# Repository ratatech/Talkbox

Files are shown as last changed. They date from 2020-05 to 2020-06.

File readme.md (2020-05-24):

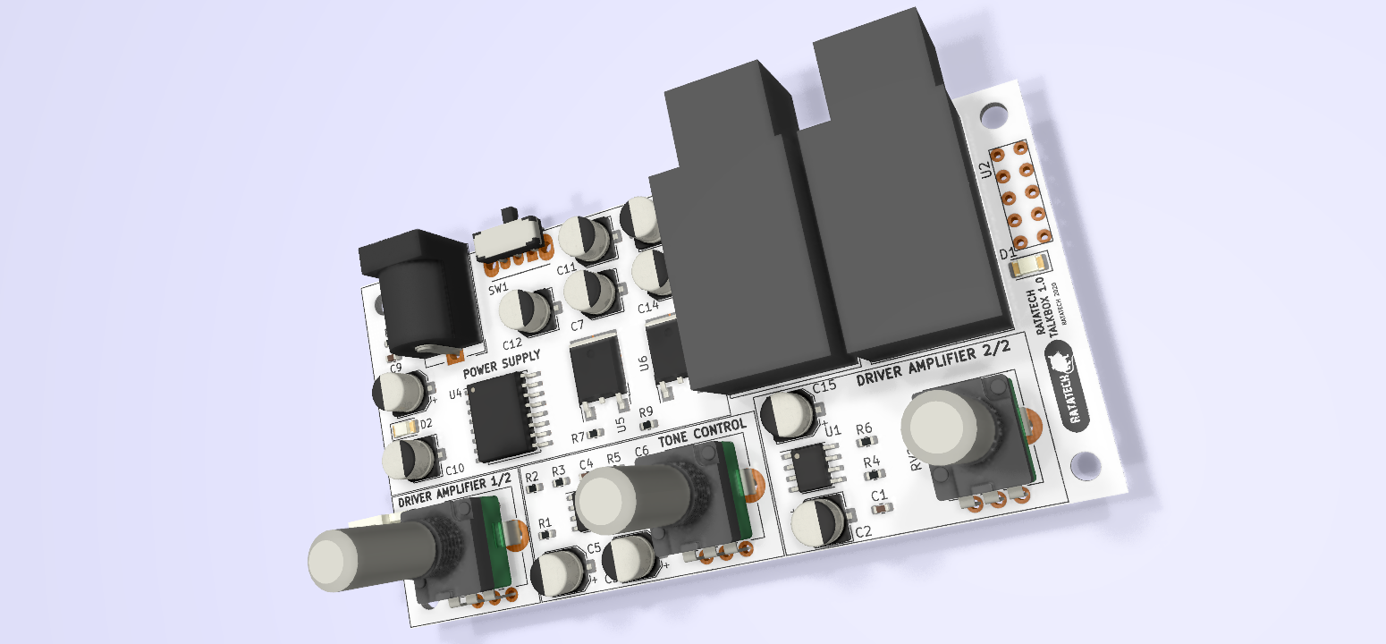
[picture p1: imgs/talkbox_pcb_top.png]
Ratatech Talkbox pcb top view


# Ratatech Talkbox

This repository contains mainly the PCB design files for the Ratatech Talkbox unit. 

DESCRIPTION WIP.

## Files

* [datasheets](./datasheets) 	Datasheets of some of the components and schematics used in this project.
* [imgs](./imgs) 				Images used in the design and captures or the 3d models/final pcb.
* [kicad](./kicad) 				Main Kicad project directory. Including schematics and pcb.

---

## License



- **[MIT license](http://opensource.org/licenses/mit-license.php)**

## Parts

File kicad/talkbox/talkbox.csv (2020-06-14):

Reference | Quantity | Value | Footprint | Datasheet | Mouser part
C10 | 1 | 0.002uF | Capacitor_SMD:C_0603_1608Metric | ~ | 603-CC603KRX7R9BB202
C11 C5 C4 | 3 | 100uF | Capacitor_SMD:CP_Elec_5x5.3 | ~ | 661-EMZJ6R3A101ME61G
C13 C12 C8 | 3 | 2uF | Capacitor_SMD:CP_Elec_5x5.3 | ~ | 661-EMVE630ADA3R3ME5
C15 C14 | 2 | 1uF | Capacitor_SMD:CP_Elec_5x5.3 | ~ | RVS-50V010MU-R
C3 | 1 | 6.8nF | Capacitor_SMD:C_0603_1608Metric | ~ | 710-885012206088
C6 | 1 | 10nF | Capacitor_SMD:C_0603_1608Metric | ~ | 710-885012206040
C7 | 1 | 47nF | Capacitor_SMD:C_0603_1608Metric | ~ | 140-VE470M1CTR0505
C9 C2 C1 | 3 | 10uF | Capacitor_SMD:CP_Elec_5x5.3 | ~ | 598-AVE106M35C12T-F
D2 D1 | 2 | LED | LED_SMD:LED_1206_3216Metric | ~ | 327-BR1101WTR
H1 H3 H2 H4 | 4 | MountingHole | MountingHole:MountingHole_3mm | ~
J1 J4 | 2 | AudioJack2 | Connector_Audio_Extended:Jack_6.35mm_Neutrik_NRJ4HF-1_Horizontal | ~ | 550-10284G
J2 | 1 | Barrel_Jack_Switch | Connector_BarrelJack:BarrelJack_CUI_PJ-102AH_Horizontal | ~ | 490-PJ-102BH
J3 | 1 | Conn_02x04_Odd_Even | Connector_PinHeader_2.54mm:PinHeader_2x04_P2.54mm_Vertical | ~
R1 | 1 | 1000k | Resistor_SMD:R_0603_1608Metric | ~ | 667-ERJ-3GEYJ105V
R2 | 1 | 2k | Resistor_SMD:R_0603_1608Metric | ~ | 71-CRCW06032K00FKEAC
R3 | 1 | 47K | Resistor_SMD:R_0603_1608Metric | ~ | 71-CRCW060347K0FKEAC
R5 R4 | 2 | 22K | Resistor_SMD:R_0603_1608Metric | ~ | 71-CRCW060322K0FKEAC
R6 | 1 | 240K | Resistor_SMD:R_0603_1608Metric | ~ | 652-CR0603FX-2403ELF
R8 R7 | 2 | 470 | Resistor_SMD:R_0603_1608Metric | ~ | 71-CRCW0603470RFKEAC
RV2 RV1 | 2 | 20K | Potentiometer_THT:Potentiometer_Alps_RK09K_Single_Vertical | ~ | 652-PTV09A-4030UB203
RV3 | 1 | 10K | Potentiometer_THT:Potentiometer_Alps_RK09K_Single_Vertical | ~ | 652-PTV09A-4025FB103
SW1 | 1 | SW_SPST | Button_Switch_THT:SW_CuK_OS102011MA1QN1_SPDT_Angled | ~ | 611-OS102011MA1QN1
U1 | 1 | TL071 | Package_SO:SOIC-8_3.9x4.9mm_P1.27mm | http://www.ti.com/lit/ds/symlink/tl071.pdf | 511-TL071CDT
U2 | 1 | logo | imgs:ratatech_bitmap_10x2.8mm
U3 | 1 | LT1054xSOIC16 | Package_SO:SOIC-16W_7.5x10.3mm_P1.27mm |  | 595-LT1054CDWR
U4 | 1 | SW_3PDT | Connector_PinHeader_2.54mm:PinHeader_2x05_P2.54mm_Vertical |  | 612-FS573PLT2B2M1QE
U5 | 1 | LM7812_TO220 | Package_TO_SOT_SMD:ATPAK-2 | http://www.fairchildsemi.com/ds/LM/LM7805.pdf | 511-L78M12CDT-TR
U6 | 1 | LM7912_TO220 | Package_TO_SOT_SMD:ATPAK-2 | http://www.fairchildsemi.com/ds/LM/LM7905.pdf | 512-KA79M12RTF

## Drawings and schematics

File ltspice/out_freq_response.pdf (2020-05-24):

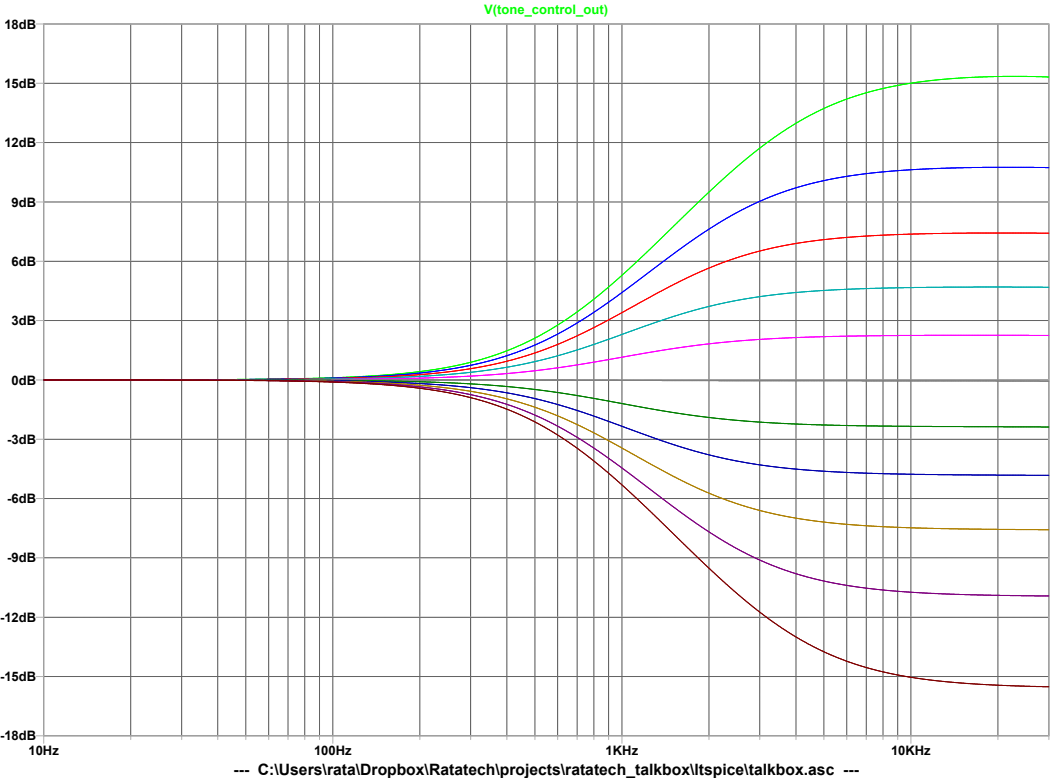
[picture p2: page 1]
1KHz; 10KHz; V(tone_control_out)

--- C:\Users\rata\Dropbox\Ratatech\projects\ratatech_talkbox\ltspice\talkbox.asc ---

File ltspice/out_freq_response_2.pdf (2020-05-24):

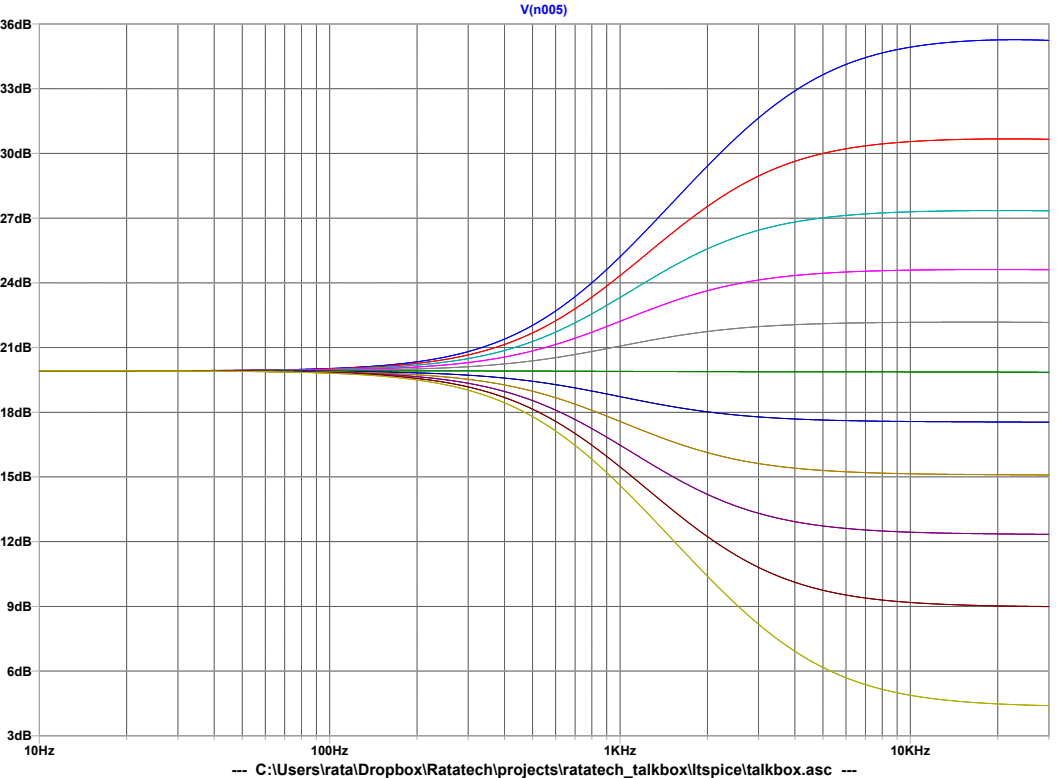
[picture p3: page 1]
1KHz; 10KHz

--- C:\Users\rata\Dropbox\Ratatech\projects\ratatech_talkbox\ltspice\talkbox.asc ---

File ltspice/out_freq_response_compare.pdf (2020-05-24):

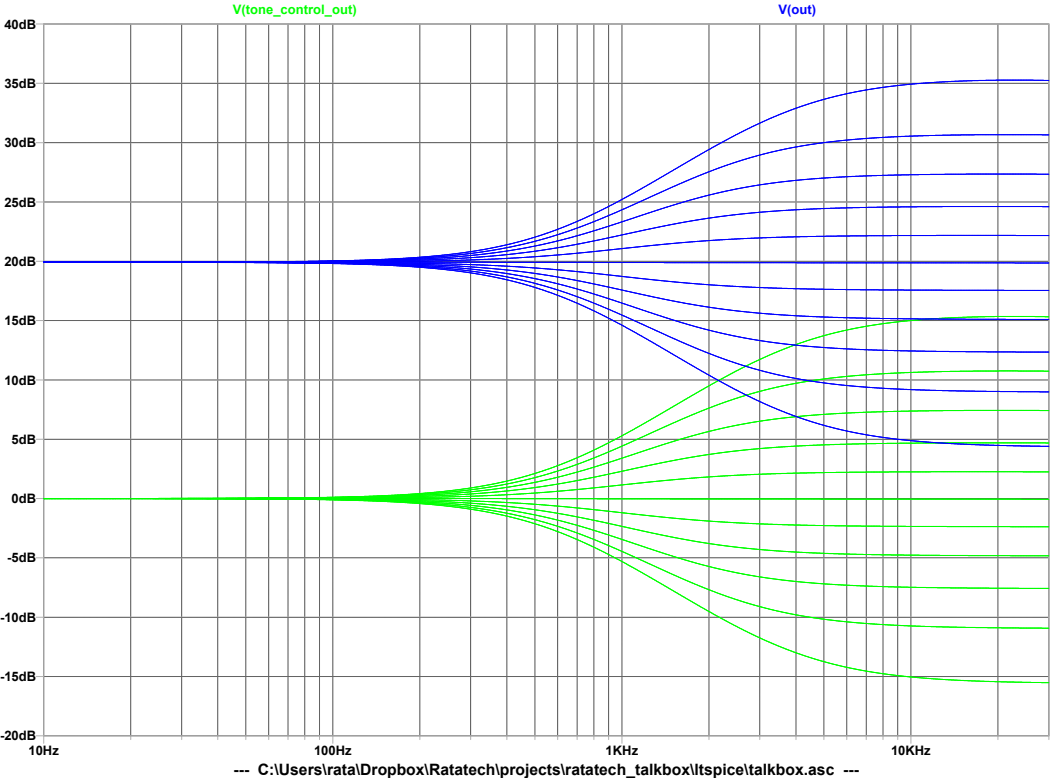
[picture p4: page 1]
1KHz; 10KHz; V(tone_control_out); V(out)

--- C:\Users\rata\Dropbox\Ratatech\projects\ratatech_talkbox\ltspice\talkbox.asc ---

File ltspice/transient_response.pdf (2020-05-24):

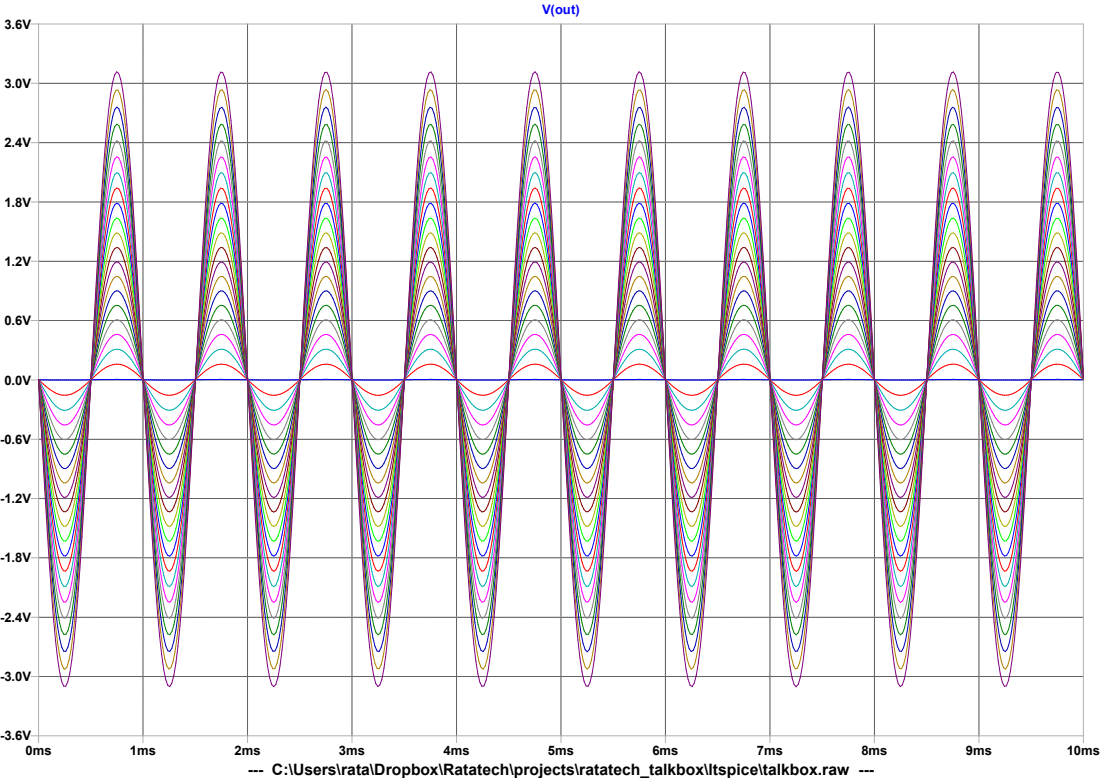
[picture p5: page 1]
V(out)

--- C:\Users\rata\Dropbox\Ratatech\projects\ratatech_talkbox\ltspice\talkbox.raw ---

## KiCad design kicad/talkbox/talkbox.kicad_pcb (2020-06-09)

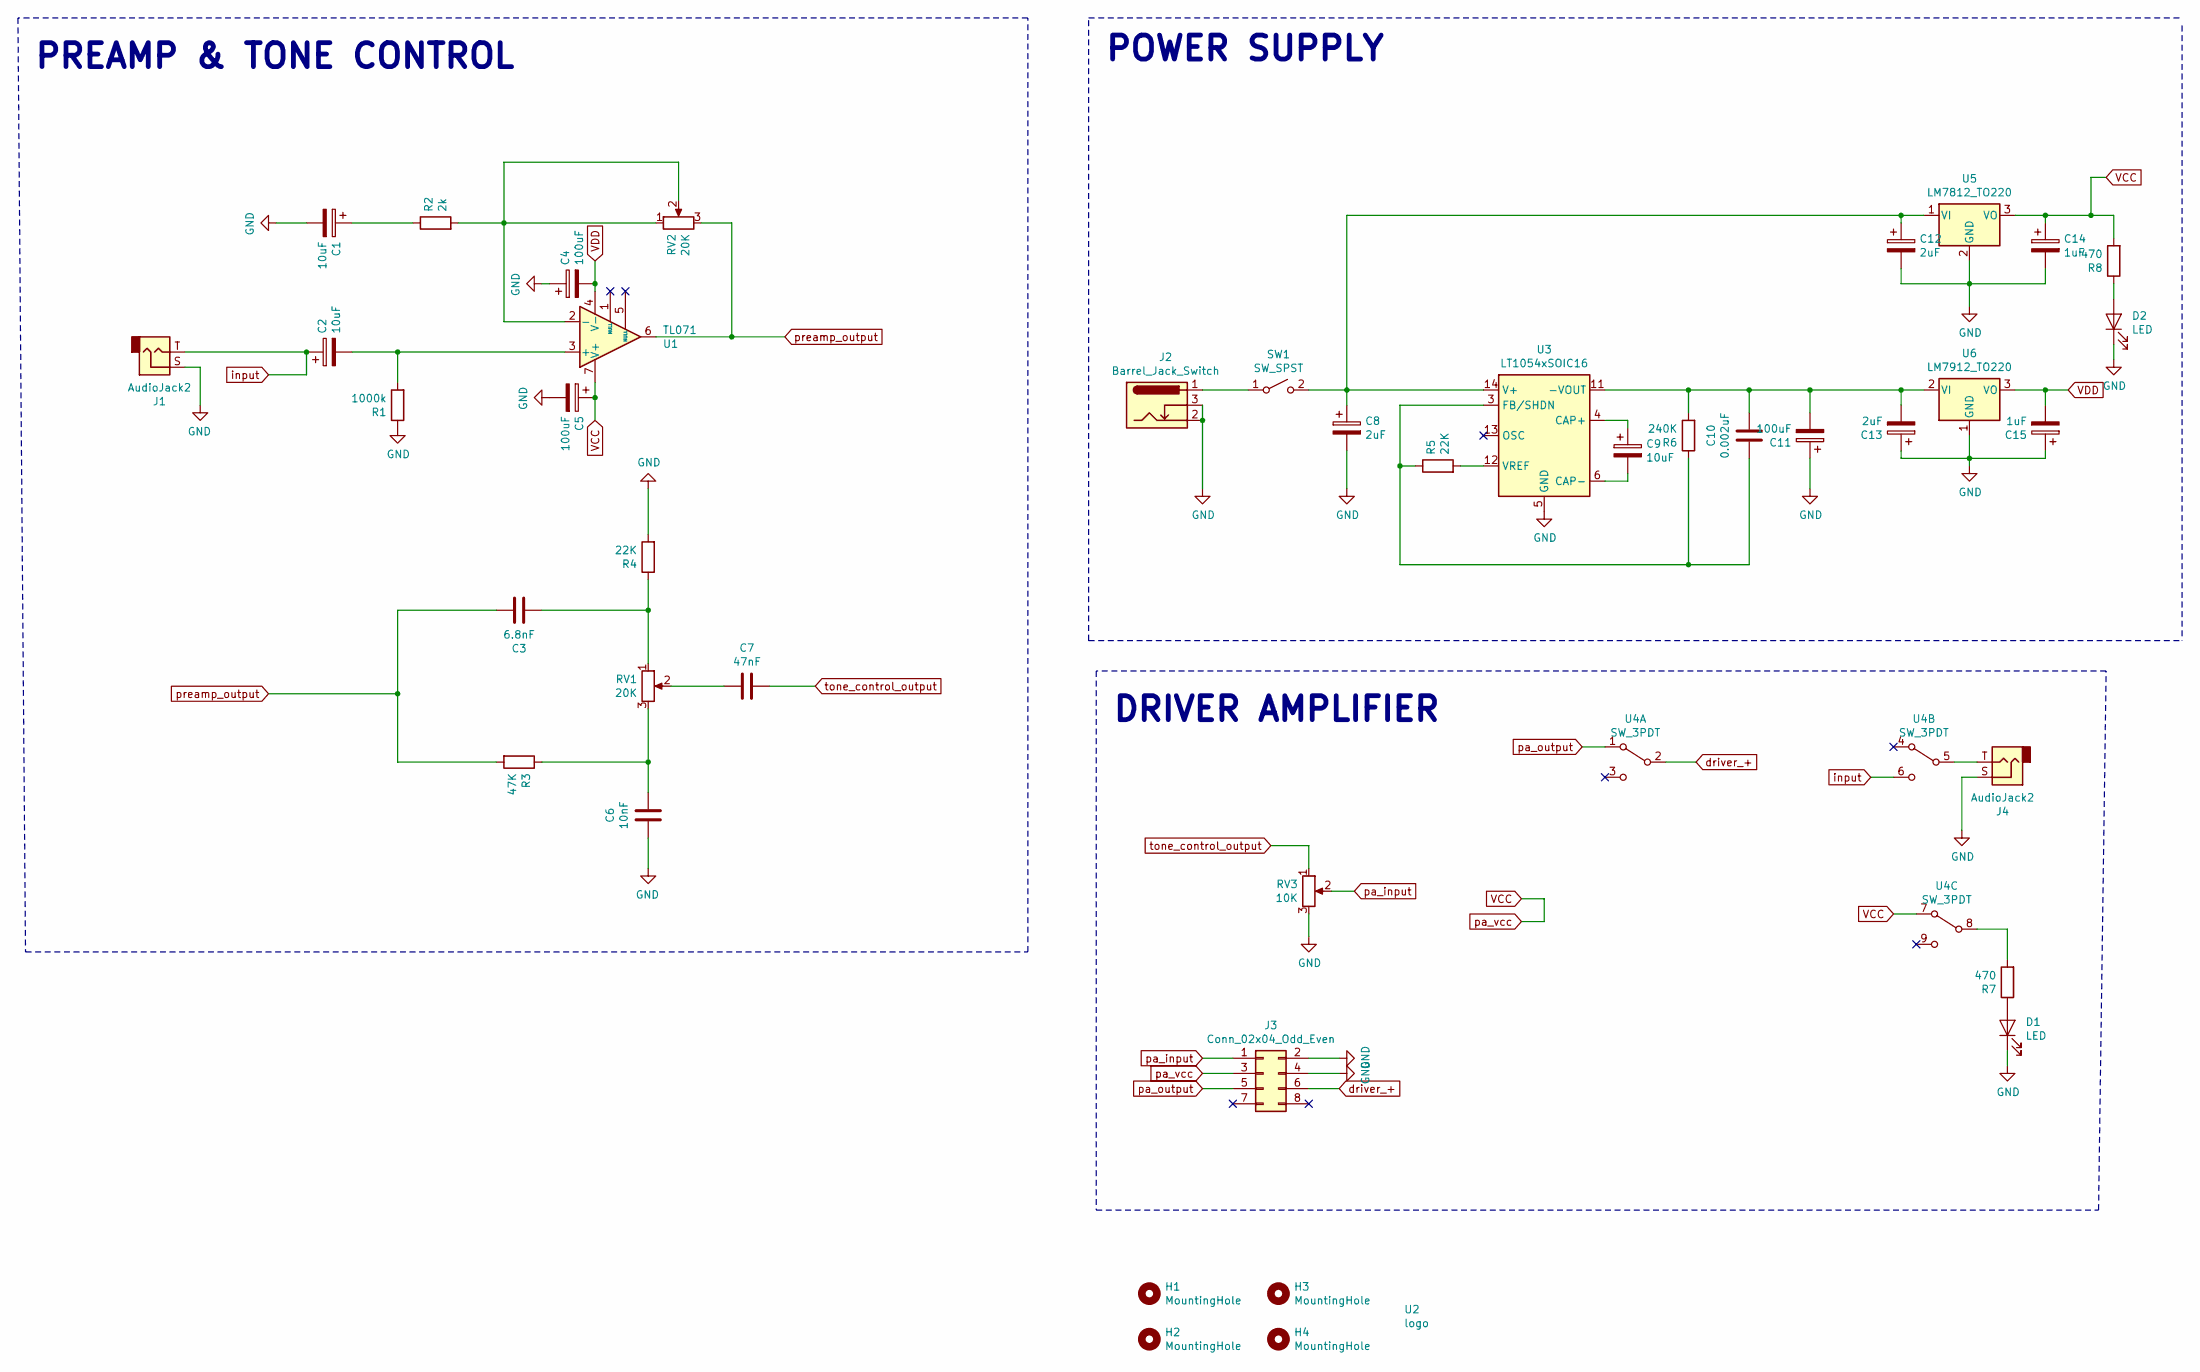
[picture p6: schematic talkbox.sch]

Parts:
C1, C2, C9: 10uF; CP_Elec_5x5.3
C3: 6.8nF; C_0603_1608Metric
C4, C5, C11: 100uF; CP_Elec_5x5.3
C6: 10nF; C_0603_1608Metric
C7: 47nF; C_0603_1608Metric
C8, C12, C13: 2uF; CP_Elec_5x5.3
C10: 0.002uF; C_0603_1608Metric
C14, C15: 1uF; CP_Elec_5x5.3
D1, D2: LED; LED_1206_3216Metric
H1, H2, H3, H4: MountingHole; MountingHole_3mm
J1, J4: AudioJack2; Jack_6.35mm_Neutrik_NRJ4HF-1_Horizontal
J2: Barrel_Jack_Switch; BarrelJack_CUI_PJ-102AH_Horizontal
J3: Conn_02x04_Odd_Even; PinHeader_2x04_P2.54mm_Vertical
R1: 1000k; R_0603_1608Metric
R2: 2k; R_0603_1608Metric
R3: 47K; R_0603_1608Metric
R4, R5: 22K; R_0603_1608Metric
R6: 240K; R_0603_1608Metric
R7, R8: 470; R_0603_1608Metric
RV1, RV2: 20K; Potentiometer_Alps_RK09K_Single_Vertical
RV3: 10K; Potentiometer_Alps_RK09K_Single_Vertical
SW1: SW_SPST; SW_CuK_OS102011MA1QN1_SPDT_Angled
U1: TL071; SOIC-8_3.9x4.9mm_P1.27mm
U2: logo; ratatech_bitmap_10x2.8mm
U3: LT1054xSOIC16; SOIC-16W_7.5x10.3mm_P1.27mm
U4: SW_3PDT; PinHeader_2x05_P2.54mm_Vertical
U5: LM7812_TO220; ATPAK-2
U6: LM7912_TO220; ATPAK-2

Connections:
GND: C1.2, C4.1, C5.2, C6.2, C8.2, C11.1, C12.2, C13.1, C14.2, C15.1, D1.1 (K), D2.1 (K), J1.S, J2.2, J2.3, J3.2, J3.4, J4.S, R1.1, R4.2, RV3.3, U3.5 (GND), U5.2 (GND), U6.1 (GND)
unnamed: C1.1, R2.1
unnamed: C2.2, R1.2, U1.3 (+)
unnamed: C3.2, R4.1, RV1.1
unnamed: C6.1, R3.1, RV1.3
unnamed: C7.2, RV1.2
unnamed: C9.1, U3.4 (CAP+)
unnamed: C9.2, U3.6 (CAP-)
unnamed: C10.1, C11.2, C13.2, R6.2, U3.11 (-VOUT), U6.2 (VI)
unnamed: C10.2, R5.1, R6.1, U3.3 (FB/SHDN)
unnamed: C8.1, C12.1, SW1.2 (B), U3.14 (V+), U5.1 (VI)
unnamed: D1.2 (A), R7.1
unnamed: D2.2 (A), R8.1
unnamed: J2.1, SW1.1 (A)
unnamed: J4.T, U4.5 (B)
unnamed: R2.2, RV2.1, RV2.2, U1.2 (-)
unnamed: R5.2, U3.12 (VREF)
unnamed: R7.2, U4.8 (B)
VCC: C5.1, C14.1, J3.3, R8.2, U1.7 (V+), U4.7 (A), U5.3 (VO)
VDD: C4.2, C15.2, U1.4 (V-), U6.3 (VO)
driver_+: J3.6, U4.2 (B)
input: C2.1, J1.T, U4.6 (C)
pa_input: J3.1, RV3.2
pa_output: J3.5, U4.1 (A)
preamp_output: C3.1, R3.2, RV2.3, U1.6
tone_control_output: C7.1, RV3.1

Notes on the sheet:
PREAMP & TONE CONTROL
POWER SUPPLY
DRIVER AMPLIFIER

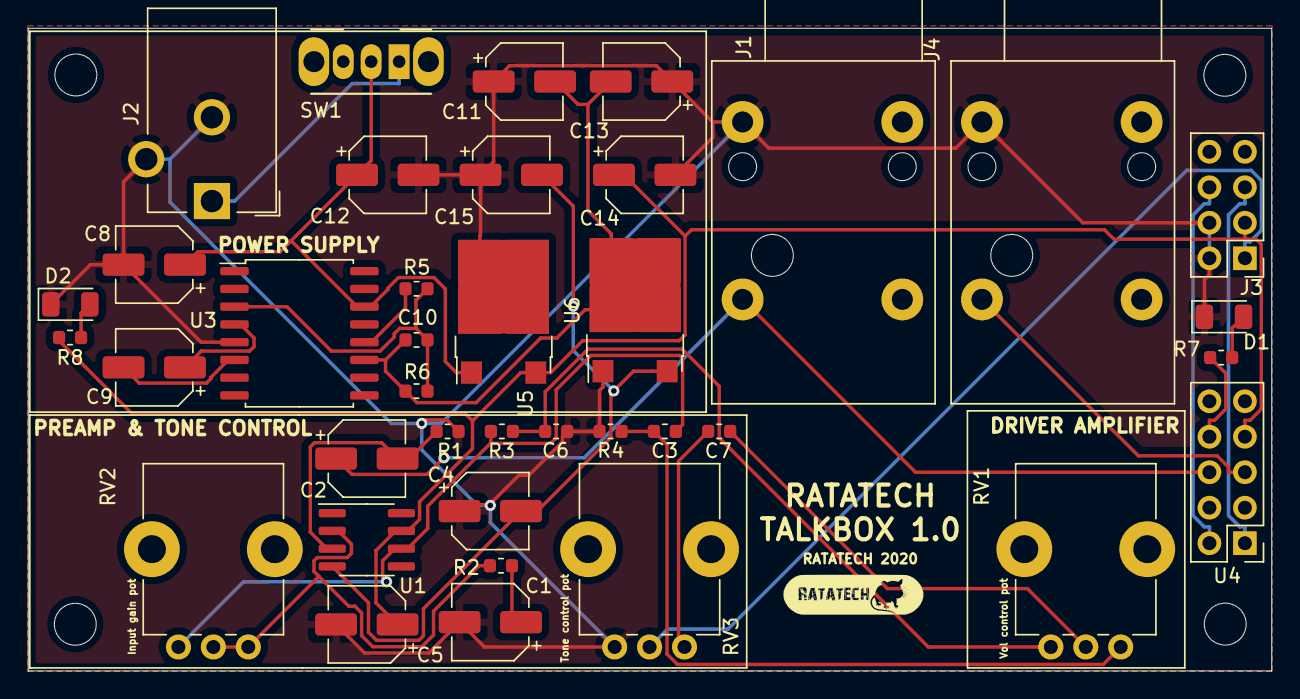
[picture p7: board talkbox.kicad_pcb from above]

Board: 2 copper layers, 89.0 x 46.0 mm, 43 parts (0 on the bottom side), 26 nets.

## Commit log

2020-05-24 Init repo
    [talkbox.kicad_pcb, talkbox.sch]
2020-05-24 Added kicad libraries and updated pcb
    [talkbox.kicad_pcb]
2020-05-24 Added gitignore
    [talkbox.kicad_pcb, talkbox.sch]
2020-05-24 First time routing
    [talkbox.dsn, talkbox.kicad_pcb]
2020-05-25 Added tl072 and preamp stage
    [talkbox.kicad_pcb, talkbox.sch]
2020-05-28 Removed lm386 based power amplifier and adapted tone control
    [talkbox.dsn, talkbox.kicad_pcb, talkbox.sch]
2020-06-07 Changed preamp capacitors to electrolytics
    [talkbox.kicad_pcb, talkbox.sch]
2020-06-07 Re-labeled drive- to GND
    [talkbox.dsn, talkbox.kicad_pcb, talkbox.sch]
2020-06-09 PCB done v1.0. Generated gerbers for fab
    [talkbox-B_Cu.gbl, talkbox-B_Mask.gbs, talkbox-B_Paste.gbp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]
2020-06-11 Added partially mouser part numbers
    [talkbox.csv, talkbox.sch]
2020-06-14 Finished BOM with mouser part numbers
    [talkbox.csv, talkbox.sch]
